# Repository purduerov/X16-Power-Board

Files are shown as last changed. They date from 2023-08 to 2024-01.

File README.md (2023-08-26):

# Readme for X16-Power-Slab
This board turns 48V into 12 V and 5 V

Whenever you make a new part, download the datasheet and save it here _**and**_ with the part in the parts library

Always pull other people's changes before beginning to work
`git pull`

Be sure to push your changes after  working on them. Run:
1. `git add .` to add any files in this directory or a subdirectory
or `git add -u` to add any modified files
2. (Optional) `git clean -nX` to see what ignored files can be removed
	`git clean -fX` removes ignored files (Eagle backups)
3. `git commit -m "helpful commit message"` with a description of the work that you did
4. `git push` to push your work to github

Other helpful commands
* `git status` says information about modified and staged files
* `git log` shows the recent commits of the repository
* `git log filename.extension` show the recent commits for just that file
* `git checkout first-couple-letter-of-commit-id` lets you go back to a previous version
* `git checkout master` brings you back to the latest commit
* `git tag` lists the tags
* `git tag -a orderX -m "the version of the board placed for the X'th order"` tag a specific commit
* `git push --tags` needed to push tags to remote
* `git show orderX` show the commit log for the given tag
* `git checkout orderX` go back and interact with the files at the tagged commit

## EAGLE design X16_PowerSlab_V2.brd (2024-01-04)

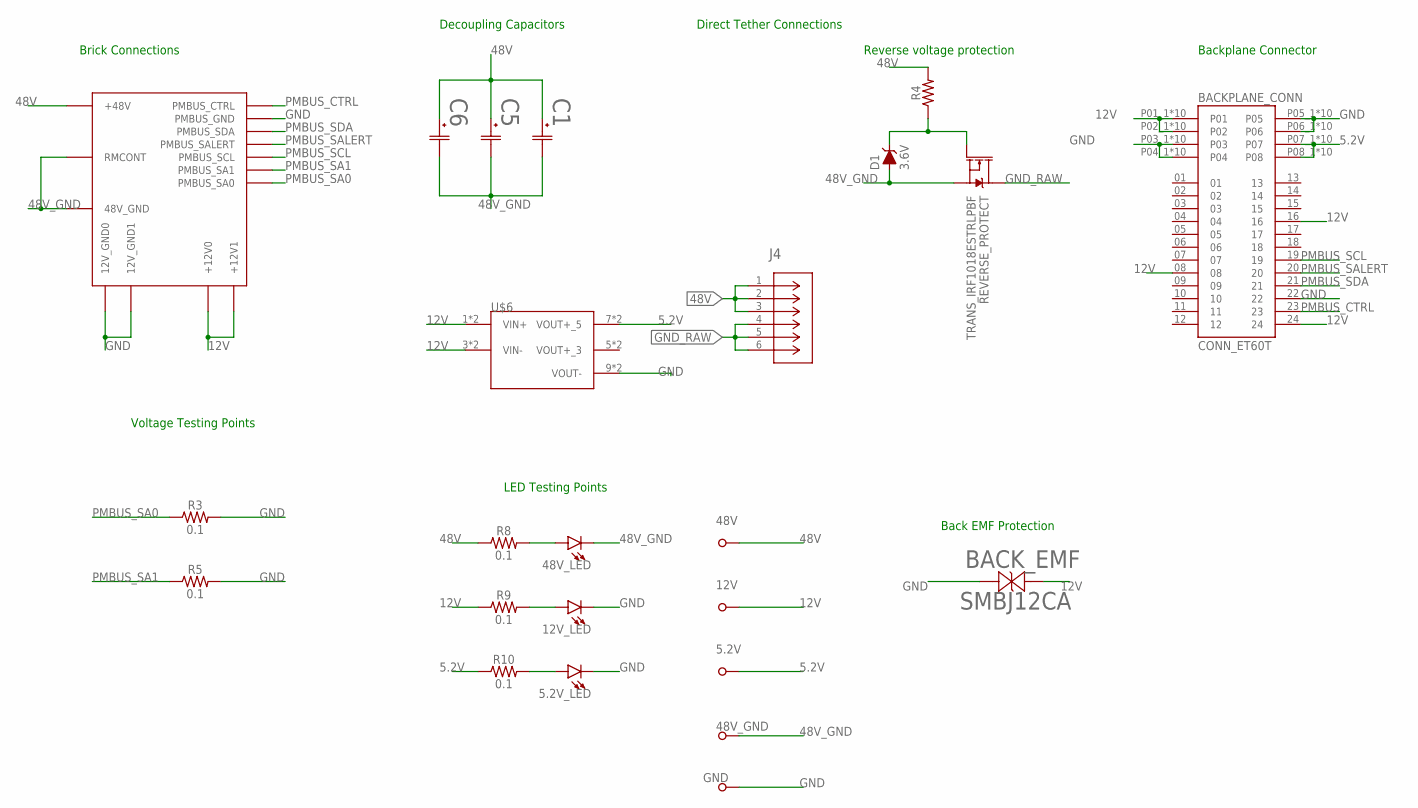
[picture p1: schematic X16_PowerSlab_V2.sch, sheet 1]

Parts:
5.2V, 12V, 48V_GND: TESTPOINT_5.04MM
5.2V_LED: 5.2V; CHIPLED_0805
12V_LED: 12V; CHIPLED_0805
48V: 48V; TESTPOINT_5.04MM
48V_LED: 48V; CHIPLED_0805
BACKPLANE_CONN: CONN_ET60T; SAMTEC_ET60T-D04-3-08-D04-X-R1-S
BACK_EMF: SMBJ12CA; SMBJSERIES_LTF
BMR480_POWERBRICK: CONN_BMR480_BRICK
C1, C5, C6: UCM1H331MNL1GS; CAP_UCD_10X10_NCH
D1: 3.6V; SOD-323
GND: TESTPOINT_5.04MM
J4: 796636-6; CON6_P5MM_VER_TERM-BLK_TYC
R3, R5, R8, R9, R10: 0.1; 0603
R4: 0603
REVERSE_PROTECT: TRANS_IRF1018ESTRLPBF; D2PAK
U$6: CONN_DISTRIBUTION_TO_CONVERSION; TSW-105-05-G-S(D-C)

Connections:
5.2V: 5.2V.TP, BACKPLANE_CONN.P07_1 (P07), BACKPLANE_CONN.P07_2 (P07), BACKPLANE_CONN.P07_3 (P07), BACKPLANE_CONN.P07_4 (P07), BACKPLANE_CONN.P07_5 (P07), BACKPLANE_CONN.P07_6 (P07), BACKPLANE_CONN.P07_7 (P07), BACKPLANE_CONN.P07_8 (P07), BACKPLANE_CONN.P07_9 (P07), BACKPLANE_CONN.P07_10 (P07), BACKPLANE_CONN.P08_1 (P08), BACKPLANE_CONN.P08_2 (P08), BACKPLANE_CONN.P08_3 (P08), BACKPLANE_CONN.P08_4 (P08), BACKPLANE_CONN.P08_5 (P08), BACKPLANE_CONN.P08_6 (P08), BACKPLANE_CONN.P08_7 (P08), BACKPLANE_CONN.P08_8 (P08), BACKPLANE_CONN.P08_9 (P08), BACKPLANE_CONN.P08_10 (P08), R10.1, U$6.7 (VOUT+_5), U$6.8 (VOUT+_5); also elsewhere on the board
12V: 12V.TP, BACKPLANE_CONN.08, BACKPLANE_CONN.16, BACKPLANE_CONN.24, BACKPLANE_CONN.P01_1 (P01), BACKPLANE_CONN.P01_2 (P01), BACKPLANE_CONN.P01_3 (P01), BACKPLANE_CONN.P01_4 (P01), BACKPLANE_CONN.P01_5 (P01), BACKPLANE_CONN.P01_6 (P01), BACKPLANE_CONN.P01_7 (P01), BACKPLANE_CONN.P01_8 (P01), BACKPLANE_CONN.P01_9 (P01), BACKPLANE_CONN.P01_10 (P01), BACKPLANE_CONN.P02_1 (P02), BACKPLANE_CONN.P02_2 (P02), BACKPLANE_CONN.P02_3 (P02), BACKPLANE_CONN.P02_4 (P02), BACKPLANE_CONN.P02_5 (P02), BACKPLANE_CONN.P02_6 (P02), BACKPLANE_CONN.P02_7 (P02), BACKPLANE_CONN.P02_8 (P02), BACKPLANE_CONN.P02_9 (P02), BACKPLANE_CONN.P02_10 (P02), BACK_EMF.1, BMR480_POWERBRICK.PIN7 (+12V1), BMR480_POWERBRICK.PIN8 (+12V0), R9.1, U$6.1 (VIN+), U$6.2 (VIN+), U$6.3 (VIN-), U$6.4 (VIN-); also elsewhere on the board
48V: 48V.TP, BMR480_POWERBRICK.PIN1 (+48V), C1.1, C5.1, C6.1, J4.1, J4.2, J4.3, R4.2, R8.1
48V_GND: 48V_GND.TP, 48V_LED.C, BMR480_POWERBRICK.PIN2 (RMCONT), BMR480_POWERBRICK.PIN3 (48V_GND), C1.2, C5.2, C6.2, D1.A, REVERSE_PROTECT.2 (S)
GND: 5.2V_LED.C, 12V_LED.C, BACKPLANE_CONN.22, BACKPLANE_CONN.P03_1 (P03), BACKPLANE_CONN.P03_2 (P03), BACKPLANE_CONN.P03_3 (P03), BACKPLANE_CONN.P03_4 (P03), BACKPLANE_CONN.P03_5 (P03), BACKPLANE_CONN.P03_6 (P03), BACKPLANE_CONN.P03_7 (P03), BACKPLANE_CONN.P03_8 (P03), BACKPLANE_CONN.P03_9 (P03), BACKPLANE_CONN.P03_10 (P03), BACKPLANE_CONN.P04_1 (P04), BACKPLANE_CONN.P04_2 (P04), BACKPLANE_CONN.P04_3 (P04), BACKPLANE_CONN.P04_4 (P04), BACKPLANE_CONN.P04_5 (P04), BACKPLANE_CONN.P04_6 (P04), BACKPLANE_CONN.P04_7 (P04), BACKPLANE_CONN.P04_8 (P04), BACKPLANE_CONN.P04_9 (P04), BACKPLANE_CONN.P04_10 (P04), BACKPLANE_CONN.P05_1 (P05), BACKPLANE_CONN.P05_2 (P05), BACKPLANE_CONN.P05_3 (P05), BACKPLANE_CONN.P05_4 (P05), BACKPLANE_CONN.P05_5 (P05), BACKPLANE_CONN.P05_6 (P05), BACKPLANE_CONN.P05_7 (P05), BACKPLANE_CONN.P05_8 (P05), BACKPLANE_CONN.P05_9 (P05), BACKPLANE_CONN.P05_10 (P05), BACKPLANE_CONN.P06_1 (P06), BACKPLANE_CONN.P06_2 (P06), BACKPLANE_CONN.P06_3 (P06), BACKPLANE_CONN.P06_4 (P06), BACKPLANE_CONN.P06_5 (P06), BACKPLANE_CONN.P06_6 (P06), BACKPLANE_CONN.P06_7 (P06), BACKPLANE_CONN.P06_8 (P06), BACKPLANE_CONN.P06_9 (P06), BACKPLANE_CONN.P06_10 (P06), BACK_EMF.2, BMR480_POWERBRICK.PIN4 (12V_GND1), BMR480_POWERBRICK.PIN5 (12V_GND0), BMR480_POWERBRICK.PIN10 (PMBUS_GND), GND.TP, R3.2, R5.2, U$6.9 (VOUT-), U$6.10 (VOUT-); also elsewhere on the board
GND_RAW: J4.4, J4.5, J4.6, REVERSE_PROTECT.3 (D)
unnamed: D1.C, R4.1, REVERSE_PROTECT.1 (G)
unnamed: 48V_LED.A, R8.2
unnamed: 12V_LED.A, R9.2
unnamed: 5.2V_LED.A, R10.2
PMBUS_CTRL: BACKPLANE_CONN.23, BMR480_POWERBRICK.PIN9 (PMBUS_CTRL)
PMBUS_SA0: BMR480_POWERBRICK.PIN15 (PMBUS_SA0), R3.1
PMBUS_SA1: BMR480_POWERBRICK.PIN14 (PMBUS_SA1), R5.1
PMBUS_SALERT: BACKPLANE_CONN.20, BMR480_POWERBRICK.PIN12 (PMBUS_SALERT)
PMBUS_SCL: BACKPLANE_CONN.19, BMR480_POWERBRICK.PIN13 (PMBUS_SCL)
PMBUS_SDA: BACKPLANE_CONN.21, BMR480_POWERBRICK.PIN11 (PMBUS_SDA)

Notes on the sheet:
Direct Tether Connections
Brick Connections
Reverse voltage protection
Backplane Connector
Voltage Testing Points
LED Testing Points
Back EMF Protection
Decoupling Capacitors

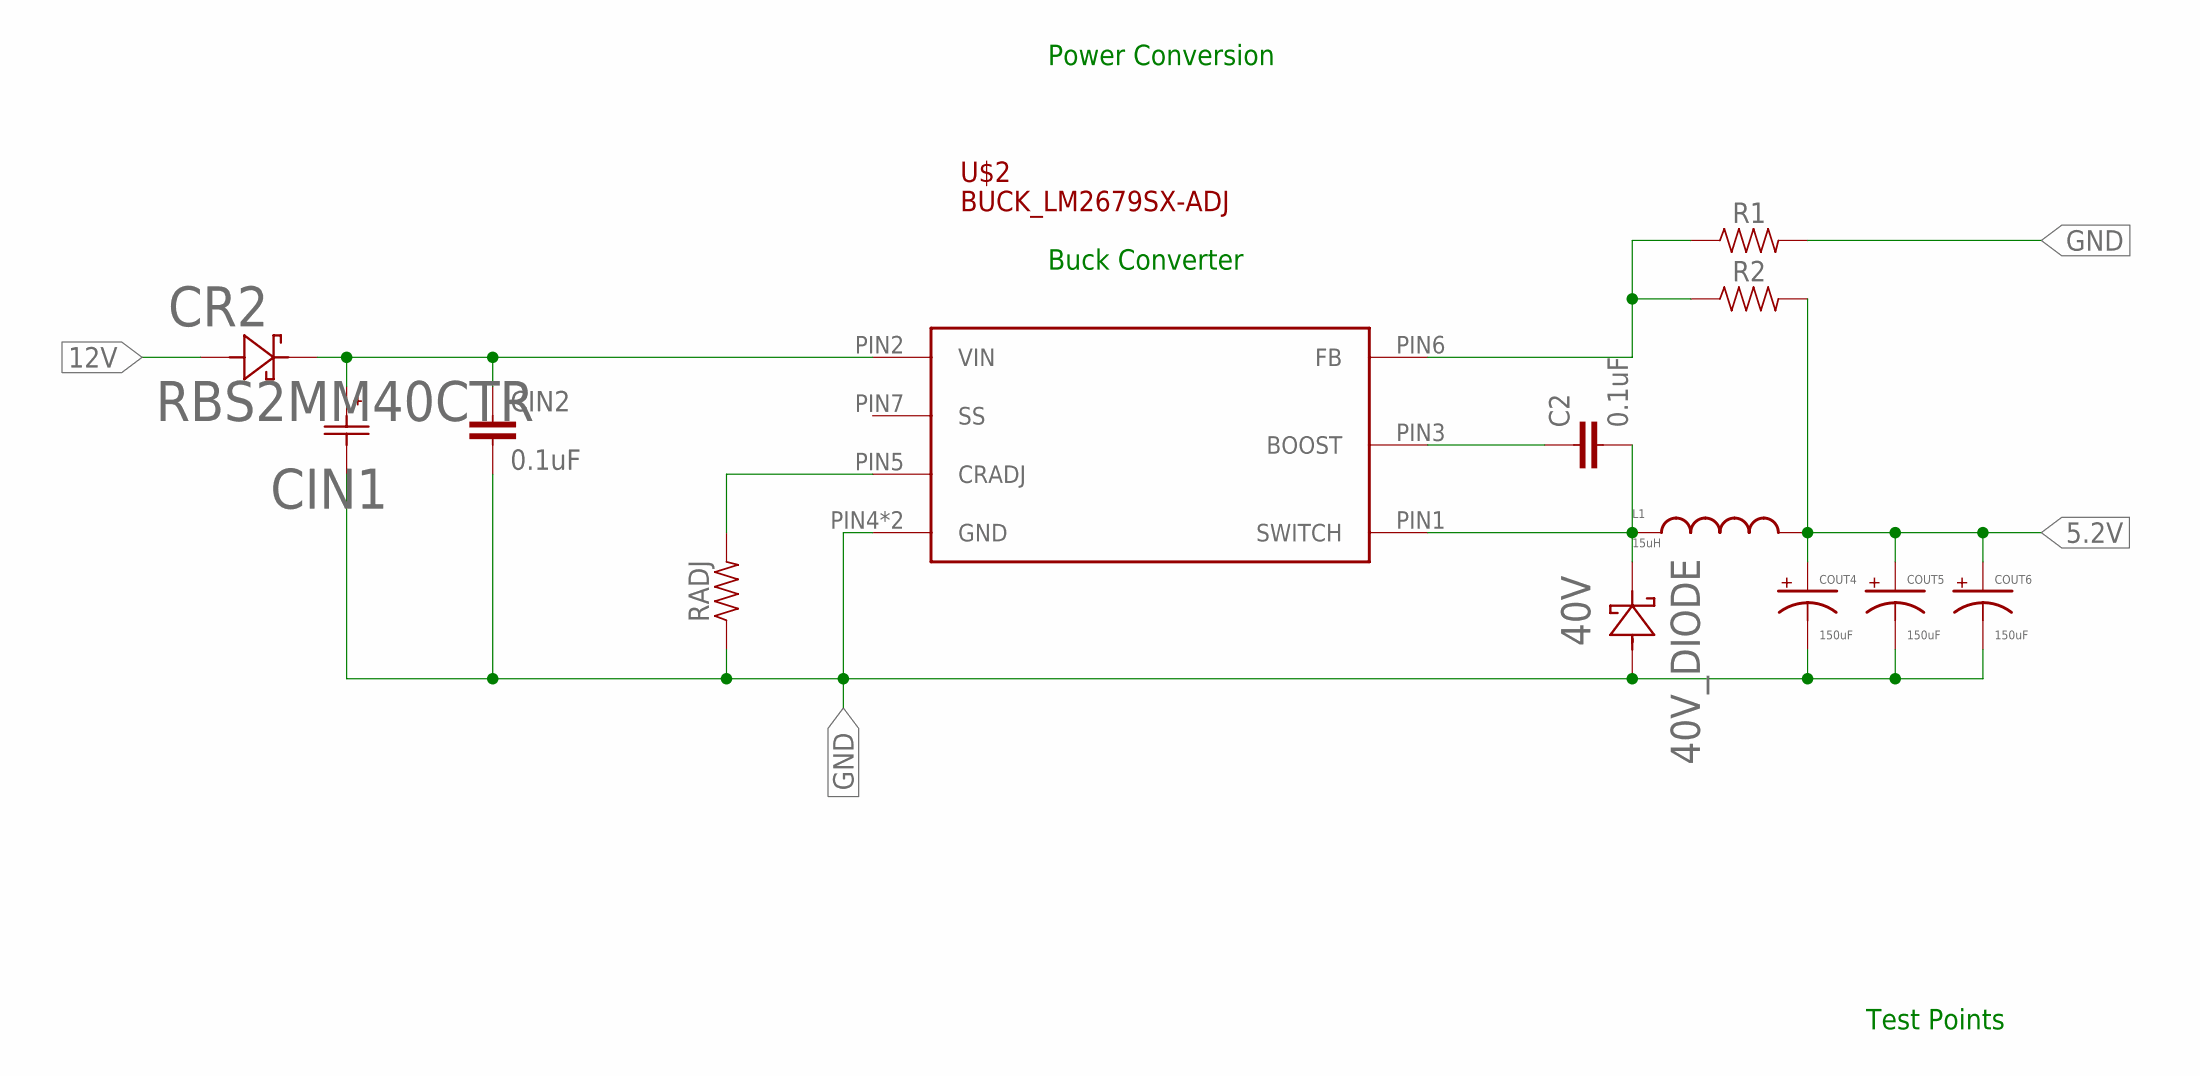
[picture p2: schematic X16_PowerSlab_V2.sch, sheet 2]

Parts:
40V_DIODE: 40V; DO214AC
C2: 0.1uF; 0603
CIN1: 594D187X0016R2T; CAP_X0016R2T_VIS
CIN2: 0.1uF; 0603
COUT4, COUT5, COUT6: 150uF; 2917(7343-31-METRIC)
CR2: RBS2MM40CTR; SDO_RBS2MM40CTR_ROM
L1: 15uH; HCMA1305
R1, R2: 0603
RADJ: 0603
U$2: BUCK_LM2679SX-ADJ; BUCK,LM2679SX-ADJ

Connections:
5.2V: COUT4.+, COUT5.+, COUT6.+, L1.2, R2.2; also elsewhere on the board
12V: CR2.2; also elsewhere on the board
GND: 40V_DIODE.A (2), CIN1.2, CIN2.2, COUT4.-, COUT5.-, COUT6.-, R1.2, RADJ.1, U$2.PIN4 (GND), U$2.PIN8 (GND); also elsewhere on the board
unnamed: C2.1, U$2.PIN3 (BOOST)
unnamed: 40V_DIODE.C (1), C2.2, L1.1, U$2.PIN1 (SWITCH)
unnamed: R1.1, R2.1, U$2.PIN6 (FB)
unnamed: RADJ.2, U$2.PIN5 (CRADJ)
VIN: CIN1.1, CIN2.1, CR2.1, U$2.PIN2 (VIN)

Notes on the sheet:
Power Conversion
Buck Converter
Test Points

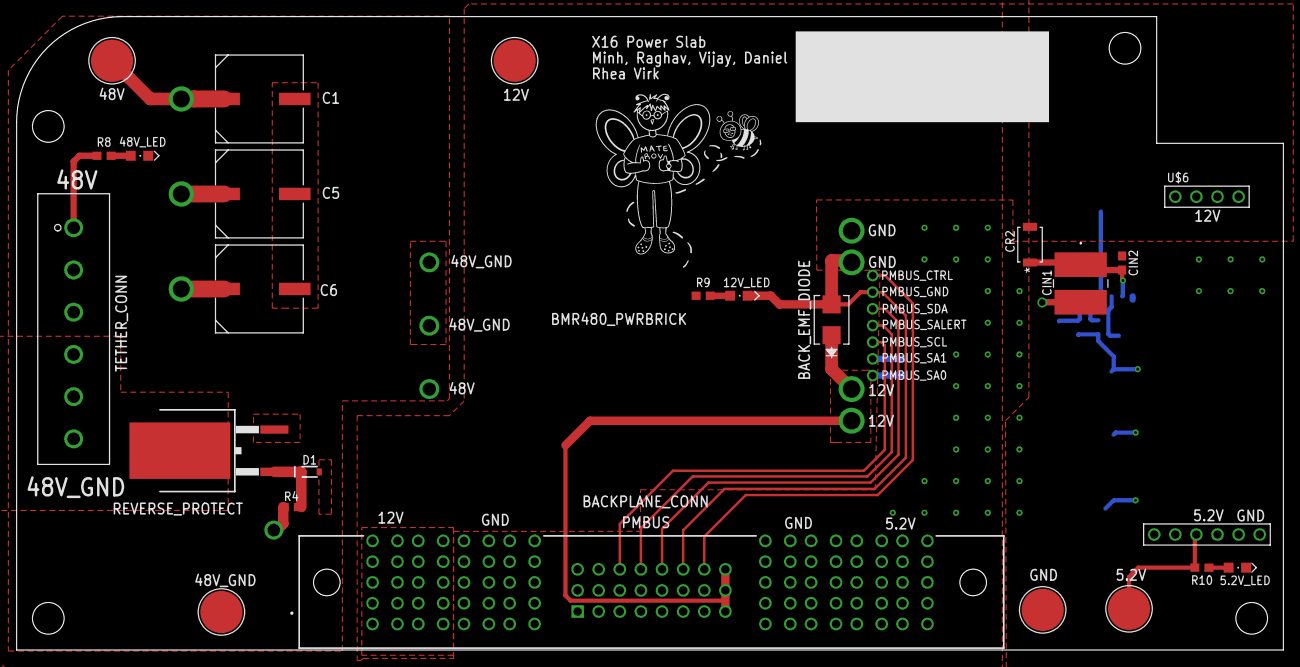
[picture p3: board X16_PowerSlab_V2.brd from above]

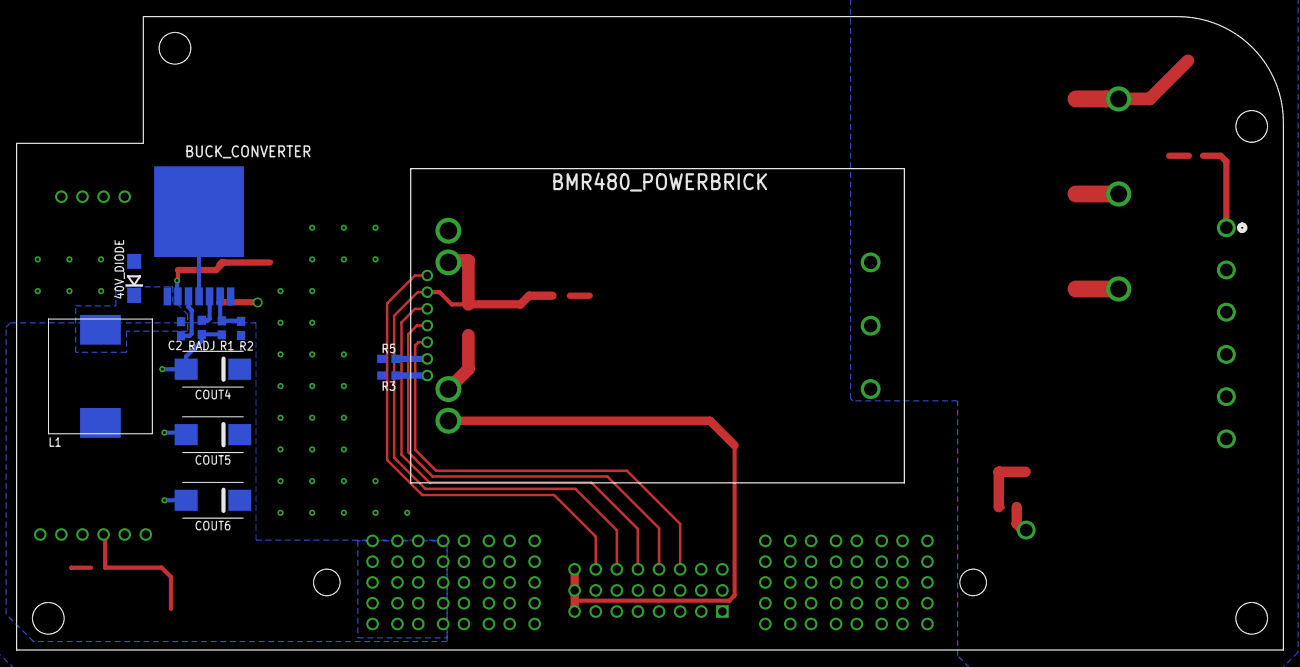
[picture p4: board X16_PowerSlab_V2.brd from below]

Board: 2 copper layers, 152.4 x 76.2 mm, 41 parts (17 on the bottom side), 21 nets.

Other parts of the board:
H1, H2, H3, H4: 6-32-HOLE

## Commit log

2023-08-30 Board Outline
    [X16-Power-Slab.brd, X16-Power-Slab.sch]
2023-08-30 changed dimensions
    [X16-Power-Slab.brd]
2023-10-05 Buck converter added
    [X16-Power-Slab.brd, X16-Power-Slab.sch]
2023-10-11 Power Conversion finished, updated Brickstribution
    [X16-Power-Slab.brd, X16-Power-Slab.sch]
2023-10-11 Updated component values, added test points
    [X16-Power-Slab.brd, X16-Power-Slab.sch]
2023-10-18 Updated reverse voltage protection
    [X16-Power-Slab.brd, X16_PowerSlab_V2.brd, X16_PowerSlab_V2.sch]
2023-10-18 Added testpoints, fixed some errors with values
    [X16_PowerSlab_V2.brd, X16_PowerSlab_V2.sch]
2023-10-19 schematic finished
    [X16_PowerSlab_V2.brd, X16_PowerSlab_V2.sch]
2023-10-19 Fixed area of board
    [X16_PowerSlab_V2.brd]
2023-10-21 Started placing components on board
    [X16_PowerSlab_V2.brd, X16_PowerSlab_V2.sch]
2023-11-04 Started placing board components
    [X16_PowerSlab_V2.brd, X16_PowerSlab_V2.sch]
2023-11-04 all components laid out
    [X16_PowerSlab_V2.brd]
2023-11-11 Added Power Conversion to Brickstribution connector
2023-11-11 set up polygons
    [X16_PowerSlab_V2.brd, X16_PowerSlab_V2.sch]
2023-11-15 worked on routing
    [X16_PowerSlab_V2.brd]
2023-11-16 updated routing
    [X16_PowerSlab_V2.brd, X16_PowerSlab_V2.sch]
2023-11-17 routing, fixed outdated components
    [X16_PowerSlab_V2.brd, X16_PowerSlab_V2.sch]
2023-11-17 updated board
    [X16_PowerSlab_V2.brd, X16_PowerSlab_V2.sch]
2023-11-18 finished polygons
    [X16_PowerSlab_V2.brd, X16_PowerSlab_V2.sch]
2023-11-29 deleted v1
    [X16-Power-Slab.brd, X16-Power-Slab.sch, X16_PowerSlab_V2.brd]
2023-12-07 Followed video, few discrepancies
    [X16_PowerSlab_V2.brd, X16_PowerSlab_V2.sch]
2023-12-07 Board finished; ran DRC
    [X16_PowerSlab_V2.brd, X16_PowerSlab_V2.sch]
2023-12-20 Labels added
    [X16_PowerSlab_V2.brd, X16_PowerSlab_V2.sch]
2023-12-20 fixed a resistor value
    [X16_PowerSlab_V2.brd, X16_PowerSlab_V2.sch]
2023-12-20 Minh Update
    [X16_PowerSlab_V2.brd, X16_PowerSlab_V2.sch]
2023-12-20 Minh Update 2
    [X16_PowerSlab_V2.brd]
2023-12-22 Minh Update 3
    [X16_PowerSlab_V2.brd, X16_PowerSlab_V2.sch]
2023-12-23 Removed the traces, and placed the address resistors.
    [X16_PowerSlab_V2.brd]
2023-12-23 Minh update 4
    [X16_PowerSlab_V2.brd, X16_PowerSlab_V2.sch]
2023-12-29 Minh Update 5
    [X16_PowerSlab_V2.brd, X16_PowerSlab_V2.sch]
2023-12-29 Minh Update 6
    [X16_PowerSlab_V2.brd]
2023-12-29 Minh Update 7
    [X16_PowerSlab_V2.brd, X16_PowerSlab_V2.sch]
2024-01-04 Minh Update 8
    [X16_PowerSlab_V2.brd, X16_PowerSlab_V2.sch]

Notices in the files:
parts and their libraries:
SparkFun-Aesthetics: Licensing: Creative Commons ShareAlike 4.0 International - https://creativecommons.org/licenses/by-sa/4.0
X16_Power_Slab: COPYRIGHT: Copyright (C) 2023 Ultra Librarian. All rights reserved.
